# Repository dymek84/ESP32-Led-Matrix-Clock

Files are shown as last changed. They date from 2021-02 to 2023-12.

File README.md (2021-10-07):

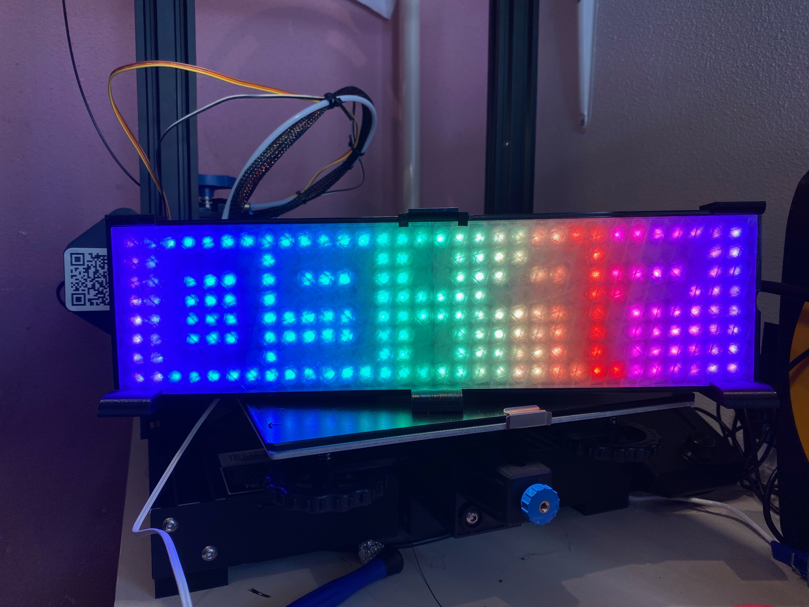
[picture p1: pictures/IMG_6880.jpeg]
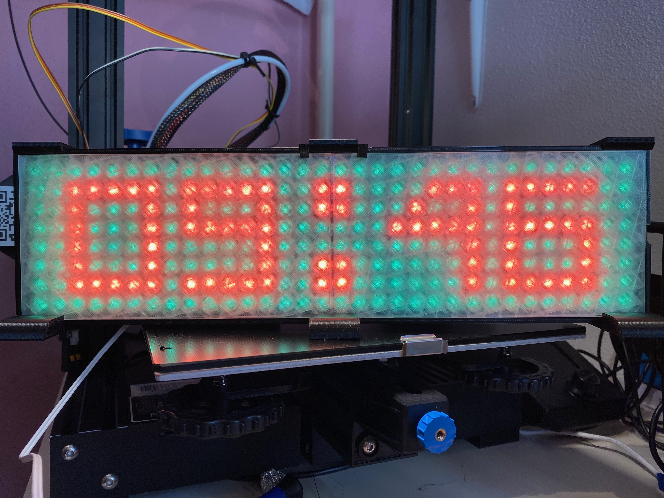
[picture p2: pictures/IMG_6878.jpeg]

(http://www.youtube.com/watch?v=N7SGHlUMIps "")

# ESP32-Led-Matrix-Clock. VERSION 2.0 since March 16-2021
A led matrix clock ran on an ESP32 using FastLED and a led matrix

# How I got to this project
Based on the LED projects by Bitluni (https://bitluni.net) I got excited to use WS2812 (or alike) LED's to create something fun.
After creating my LED Pingpong Ball light I wanted something else. So I stumbled on the LED clock video https://www.youtube.com/watch?v=7urN2OS0fjs by Thomas https://www.instructables.com/Ping-Pong-Ball-LED-Clock/ and https://www.hackster.io/news/improved-led-ping-pong-ball-clock-232a0ac06643
I loved these creations. But... (always a but), this is a BIG clock, a bit too much for my livingroom. Also these clocks run on an arduino and I wanted to use an ESP32.
# Why an ESP32? 
In this project I used: Wemos Mini D1 EPS32 and the ESP32 Devkit V1 both work ). https://www.amazon.nl/ESP-32S-Wireless-Bluetooth-Esp8266-CP2102/dp/B07NW8S1ZR
Because it has built-in WIFI, Bluetooth, DualCore, RTC and much much more. Oh, and a lot of program memory.

# Leds (WS2812 8x32 LED matrix)
Also, I was looking into alternatives to ping-pong balls and LED-strips with smaller LED spacings. The ones used in the projects above are all 30 LEDS per meter. Luckely there are also LED strips with 60 and 144 LED's per meter. Downside, the pingpong balls wont fit. And while searching for these strips my eye caught an alternative, a WS2812 LED MATRIX, available in the sizes 8x8 (too small for this project, unless you buy 4), 16x16 (yes nice) and an 8x32 (great!!) version. I bought the latter. I bought mine at (https://www.tinytronics.nl/shop/en/lighting/led-digital/ws2812b-digitale-5050-rgb-led-matrix-32x8-flexible) but you can get it a lot cheaper on one of the chinese stores.  Please note. This project doesn't depend on using this specific matrix. You can create your own, or buy for example 4 8x8 LED matrices and even any other addressable LED can be used, as long as it is supported by the FastLED library (http://fastled.io).

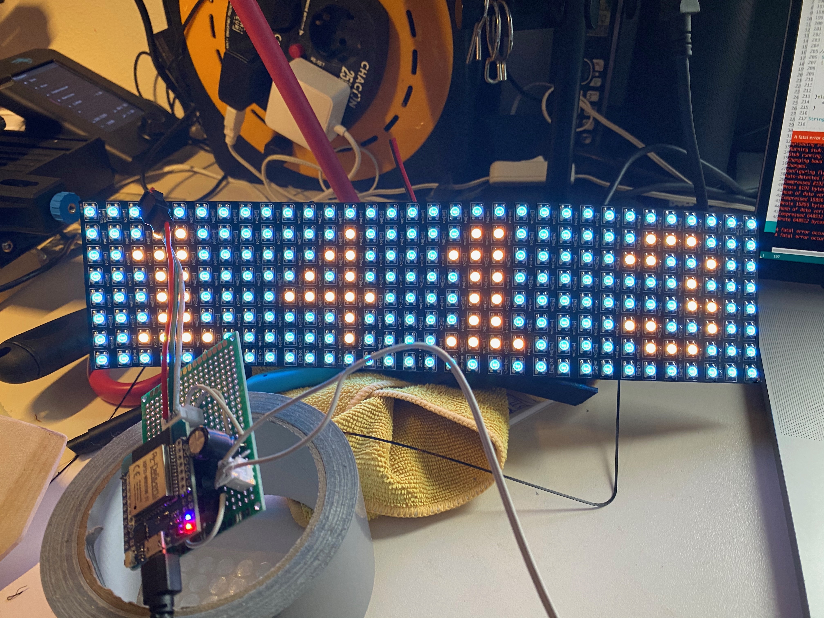
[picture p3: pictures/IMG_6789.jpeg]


# 3D printer files, equipment and settings.
As ping pong balls don't fit and as I also just bought a 3D printer, I really wanted to make use of that. After a crash course in fusion 360 design, I created an enclosure for the matrix and ESP32. An OMG, It looks great!! The Fusion 360 files (or printable obj files) will be shared here as well. For you to use and change in anyway you like. Please know, I'm not a fusion 360 specialist, by far, so non parametric, ugly sketches and a lot of .. how did I do this moments, went into designing. 
The enclosure was printed using Black PLA and the LED diffusor using Neutral (almost transparent) PLA. (neutral: https://www.123-3d.nl/PLA/1-75-mm-PLA/Neutraal-p7318.html, black: https://www.123-3d.nl/PLA/1-75-mm-PLA/Zwart-p7316.html).  
Everything was printed on a Creality Ender 3v2: https://www.123-3d.nl/3D-printers/Creality-3D-Ender-3-V2-p16058.html accomodated with a BL-touch. (Using the superb modded Marlin firmware provided by Smith3D : https://smith3d.com/ender-3-v2-bltouch-firmware-installation-guide-by-smith3d-com/)
All fusion 360 files were sliced using CURA 4.7.  As the enclosure is a little bit bigger then the printbed (32 cm vs 22.5 cm) I designed it such that it is printed in 2 pieces and glued together afterwards. The same for the diffusor. Everything was printed at standard quality (0.4 nozzle and 0.2 layer height) except for the stands, these were printed at 0.28 layer height, which didn't affect the quality because of their simplicity. 

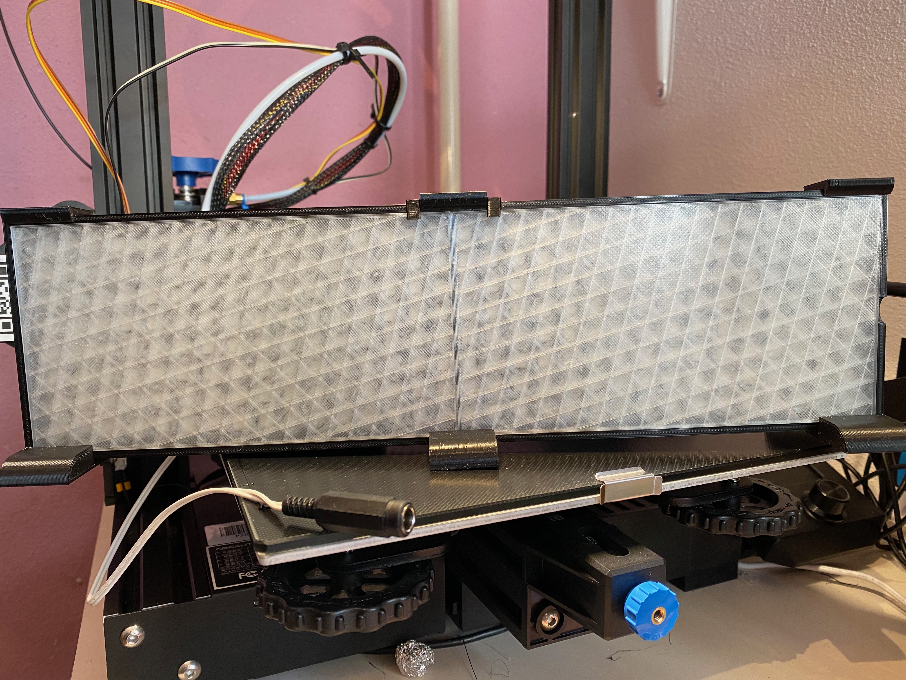
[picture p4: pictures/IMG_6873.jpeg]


# Coding and stuff
First of all, I'm not a software engineer. I did a lot of programming in the past, mostly in [R], Java, PHP and Perl. I'm a bioinformatician, who mostly does biological data analysis using scripts and a bit of ugly code. Don't expect a neatly programmed project. I tried to put comments in the code and splitted the Arduino.ino files into seperate files, each with their own 'focus'. So no libraries. In the end the arduino environment will concatenate all files into one big file and compile it. 
I used a lot of global variables. Some lineair thinking and ugly if loops. And when possible put repeated code in functions. Those are my design choices. Not the best, but they get the job done. I invite you, if you like this project, to make it better, faster and more efficient!!! 
## It is open source, but please if you make any improvements or create your own version in the end, please acknowledge me and share the code with me. 
- Use the Arduino programming environment and make sure to Add the ESP32 to your libraries and boards, see tutorial: https://randomnerdtutorials.com/installing-the-esp32-board-in-arduino-ide-windows-instructions/
- You can import my sketch in this environment. If correct, all files should be in there!! Don't change the file names (and yes, I used numbering and some numbers my be missing, this is deliberary a I might want to add stuff later on..) The order is important!! All files should be in TABS in the arduino project onces it is opened. 
- I have used a lot of libraties: Make sure you have them all installed in the arduino environment:
#include <FastLED.h>                                  // No animations without this library
#include <WiFi.h>                                     // No wifi without this library
#include "Time.h"                                     // And how about the time.. no idea what time it is without this library
#include <String>
#include <AsyncTCP.h>                                 // Webserver stuff
#include <ESPAsyncWebServer.h>                        // More webserver stuff
#include <HTTPClient.h>                               // Needed to get some information from the internetz.. .like weather data  
#include <AsyncElegantOTA.h>                          // A library to allow Over The Air Updates :)
#include <Arduino_JSON.h>                             // Often this data comes as JSON :)
#include "soc/soc.h"                                  // Used to make taksk on diferent cores
#include "soc/rtc_cntl_reg.h"
#include <Preferences.h>                              // Store the prefences in permanent memory in a much easier way than SPIFFS
#include "HTML.h"                                     // A library containing the HTML pages (included with this project)
#include "MatrixDefs.h"                               // A library containing the arrays with matrix defenitions, eg xy positions etc. IMPORTANT as
#include <map>                                        // We will use hashmaps to store Led position and color data
  
Issues I have encountered on my Mac (OSX 11.2.1) when trying to compile in arduino are...:
- Almost after every OSX update I get error messages that compiling is not possible: Run this in the terminal --> sudo xcode-select --install
- Not seeing the ESP32 on the serial port: https://www.silabs.com/developers/usb-to-uart-bridge-vcp-drivers install the correct UART drivers (2102)
- Some ESP32 (not the mini I used) have two buttons, one (boot) must be pressed when uploading your compiled sketch! The ESP32 wemos mini I used does this automatically.
- This guide: https://randomnerdtutorials.com/esp32-troubleshooting-guide/ helped me basically with all issues.

Important:
The first .ino file (called LEdMatrixESP2) contains all globals and settings for the LED types used, amount of LED's, the max current and voltage used, and on which ESP32 pin(s) the LED's are connected. Make sure everything is correct. 
More over the ledArray[XRES * YRES] is THE place to configure your matrix. It basically tells which LED number is on which X,Y coordinate. As this may differ between led matrices.  Mine for example was a up/down/down/up/up...etc configuration. This part is some hand-work. For sure somebody may have a smarter and more mathematical approach. Well this works for me.   The numberMatix stores the number characters.. Which in this case are actually 6x6 pixel characters in a 8x8 array (64). You can create your own font if you like, but just changing the 0 and 1 at specific positions. 
Also in this file you find the HTML pages that are served to configure the clock once it is up and running.

#So what does it do (or what did I implement).
1. After uploading the compiled sketch to the ESP32 or after booting up/restart..
2. The ESP32 will power-up. And after a few seconds on the top left a LED will turn on. And under that light more leds will turn. One more for every time that the ESP will try to connect to (a) your wifi router. If this after 5 tries (~15 seconds) does not work, the ESP32 will boot up as ACCESSPOINT (see 2.1)
2.1 Depending on the first time boot, there will be no WIFI (SSID,PWD) configured. So the ESP32 will start as an accesspoint. You will see it appear as: ESP32-LedMatrixClock and the password is 1234abcd.  Logon to this wifi and open the browser 192.168.4.1 will probably the IP address of the ESP32. (If this doesn't work, connect to the serial monitor, the IP-address will be shown there as wel). On this webpage, enter the station SSID (you will not see a list, so know you names), press submit. Next enter your station password and press submit. Finally press the reboot button. If you entered everyting correctly. The ESP32 can now connect to your own WIfI router.
2.2. If connected to your wifi station (router). The LED on the matrix will turn green. 
3. The ESP32 will display a 1 or 2 or 3 digit number. Those are the last 3 numbers of it's IP address. Most often the IP address will be 192.168.1.xxx (where xxx is the number on the matrix). In case you have a very different router DNS config, you should connect your clock to the serial monitor, and there the full IP address will be shown.  
4. A 3rd LED will light-up orange, this is the ESP32 tryiing to get the time from the NTP server: europe.pool.ntp.org (change NTP server if need be in the sketch).
Sometimes the NTP server doesn't respond. The ESP32 will try 5 times (~15-20 seconds) before it decides to give up and reboot. A reboot often does the trick. Also have a look at the NTP server settings.. it is now set to the NL timezone with Daylight Saving enabled.
5. If network time is configured the time will be shown on the matrix. 
6. Now you can surf to the ESP's ip address and play with the configuration, change animations, LED colors, set a night mode, or choose for a random animation to be shown at specific intervalls. 

# Work in progress: 
There are so many things I want to do. But for now this is my action list.

- DONE: Configure colors background and letters.
- DONE: Choose an animation for the background or digits.
- DONE: Set a text on the website and display it on the matrix.		
- DONE: Random animation at a given time intervall op 60, 30, 15, 1 minutes.
- DONE: Nightmode with red letters (dim) and no background. 
- DONE: Sleep and wakeup times for nightmode.. (limited to specific times for now)
- DONE: Option to globally dim the display, and seperate dimming options for characters and background.
- ONGOIN: More animation
- DONE: Access Point mode to configure WIFI 
- DONE: Show IP address on bootup
- Characters can now only be placed based on X position, not Y position yet.
- DONE: Add photo's to this page
- IMPLEMENTED: a more simple method to animate background and foreground without them inteferring..(most of the time).
- IMPLEMENTED: Light Dependent Resistor input to automticallt accomodate the brightness of the matrix to the ambient brightness
- IMPLEMENTED: New animation. Now when a minute or hour has passed the corresponding digit scrolls down and is replaced by a new digit.
- Added Over The Air (OTA) update capability.. go to the clock settings webpage http://yourclock.ip.address/update/ and upload a pre compiles binary

-- ISSUE (or not): When background is fade-down, some animations will not look as good. As a fix some background cannot be faded (even if you set it to fade) the only dimming that will always work is the overall brightness (dimming). 
-- The code for this version 2.0 is way more structured. But still at some points spaghetti.. but its faster and easier to read (more comments inline) and better use of functions().

# Wires and schema's

In the (bad) photo you see how I soldered everyting on a soldering breadboard. (5cm x 7 cm). 
On the ESP32 I soldered pins on the ground, Pin2 and 5V places. And on the right side row two pins, one on the top and one on the bottom of the outer rows. Note: Pin2 was used in version 1, for version 2 I used pin 18. You can still use 2, 18 or any other pin, just set it correct in the code!! #define DATA_PIN .. (where .. is your data pin number)
Also, now I have added a Light Dependent Resistor, on PIN 34 (again, you can choose something else). It enables the matrix to adjust the brightness according to the ambient brightness. Its based on a voltage devider schema. Resistance of the photoresistor is typically less than 80 Ohms (< 80Ω) in full light and Dark resistance is typically greater than 20 Meg Ohms (> 20MΩ) – when the photoresistor is in full darkness. IMPORTANT: You need to drill a hole in the enclosure of the CPU-holder to fit the LDR through!
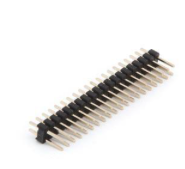
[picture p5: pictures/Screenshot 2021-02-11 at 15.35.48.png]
((Pins, also called male Pin Header,  you can break of seperate pins ;
This makes a square of pins. In this way every corner connects to the sockets on the breadboard and this makes it more stable.
On the soldering breadbord I soldered the sockets/connectors. This makes the ESP32 plug and play in case you want to add, change stuff.
I used JST XH connectors to allow easy plugin and removal of the connections to the powersupply and the matrix.
Under the ESP, I soldered the 62 Ohm resistor, this makes the data signal cleaner. I used https://github.com/Aircoookie/WLED/wiki this schema as reference.
Also a 1000uF capacitor (rated for 5V-12V and 50Watt) was used to catch possible power fluctuations. This can happen when some funcions, or effects on the matrix draw for a short time more power. This prevent so called Brownouts on the ESP32, causing it to reboot.
With 256 LED's each consuming a max of 40 mili-Amps (fully on white), you need 10 Amps at 5V (50Watt). In the code I limited to 3 Amps. This seems to be sufficient for what this clock does. It is still bright and works like a charm.
I use powerinjection.. so prevent to not feed the Leds via the ESP32, but just like I did in this schema. The Matrix that I have has 3 connectors, I powerinject over every connector to prevent voltagedrops and hence bad color representation.

Have fun....

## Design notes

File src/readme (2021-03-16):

This is version 2.0 of the Led Matrix Clock Aruino code. Many enhancements have been implemented. For better performance and more flexibility.

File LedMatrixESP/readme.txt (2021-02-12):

All *.ino files are part of one Sketch. So don't delete any of them. 
When you put everyting in a LedMatrixESP foler in the ardiuno projects folder and open LedMtrixESP.ino the other files should become visible as tabs.

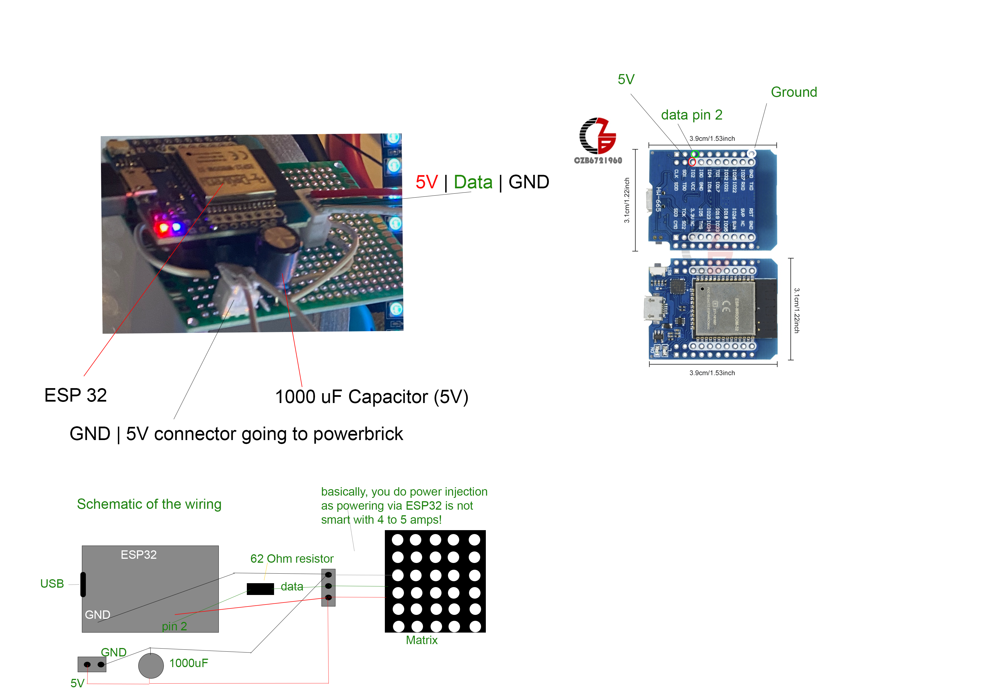
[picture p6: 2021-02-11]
pictures/ESP-schema.png

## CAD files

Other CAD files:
LedLamp v63.f3d

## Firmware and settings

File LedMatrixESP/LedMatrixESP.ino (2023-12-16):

/*
  LedMatrixESP - Clock
  This is a sketch made by: Bas van Breukelen, Arnhem Netherlands.
  This sketch is, "as it is" and made to run on a ESP32 (AZ-delivery ESP32-WROOM-32,  mini was used for development)
  The inital project was a 8x32 (256) ledMatrix, to run a a clock, updated via NTP and configurable via WiFi
  I have used effects as found on several webistes: like https://www.tweaking4all.com/hardware/arduino/adruino-led-strip-effects/#FastLEDFramework
  Plus what I can create myself. The script have been modified to fit my needs
  I also used https://randomnerdtutorials.com/esp32-esp8266-input-data-html-form/ to setup the basics of the webserver
  To make things (hopefully) more efficient I run the webserver on the second core of the EPS using this tutorial: https://randomnerdtutorials.com/esp32-dual-core-arduino-ide/
  LedMatrix: 8x32 matrix (ali-express), 256 WS2812 pixels.
  FastLed library runs it all
*/

#include <FastLED.h>
#include <WiFi.h>
#include "time.h"
#include <String>
#include <AsyncTCP.h>
#include <ESPAsyncWebServer.h>
#include <SPIFFS.h>
#include "soc/soc.h"
#include "soc/rtc_cntl_reg.h"


#define NUM_LEDS 256
#define DATA_PIN 2 //GPIO2 on ESP32
#define BRIGHTNESS 255
#define XRES 32
#define YRES 8
#define VOLTAGE 5 //5 volt strip
#define AMPS 5000 //5 AMP (or 5000 mAmp powerbrick used)

#define qsubd(x, b)  ((x>b)?b:0)                              // Digital unsigned subtraction macro. if result <0, then => 0. Otherwise, take on fixed value.
#define qsuba(x, b)  ((x>b)?x-b:0)                            // Analog Unsigned subtraction macro. if result <0, then => 0

#define maxRipples 6                                                            // Min is 2 and value has to be divisible by two because each ripple has a left and right component. This cuts down on bouncing code.


// We will store PWD and SSID in these variables.
const char* ssid;
const char* password;

//in case we cannot connect to a wifi station we will create an accesspoint and serve a page to configure wifi access.
const char* ssidAP = "ESP32-LedMatrixClock";
const char* passwordAP = "1234abcd";
boolean APmode = false;
boolean newWifiSet = false;

//wifi server
AsyncWebServer server(80);
const char* PARAM_MESSAGE = "message";


// As this led matrix clock need to know the time....
const char* ntpServer = "europe.pool.ntp.org"; //this is a general Network Time Server
const long  gmtOffset_sec = 3600; // we live in UTC+1H
const int   daylightOffset_sec = 3600; // yes NL has daylight savings
int second;
int minute;
int hour;
int day;
int month;
int year;
int weekday;
long current;
struct tm timeinfo;


// We will be doing a lot with colors, and configuring colors.. And therefore need some variables to store them
CRGB timeColor = CRGB::Red;
CRGB digitColor = CRGB::Red;
CRGB backgroundColor = CRGB::Green;
String currentAnimation;
bool breakAnimation = false;
//CRGBPalette16 currentPalette;
//TBlendType    currentBlending;
extern CRGBPalette16 myRedWhiteBluePalette;

// Palette definitions
CRGBPalette16 currentPalette;
CRGBPalette16 targetPalette;
TBlendType    currentBlending = LINEARBLEND;


uint8_t hue = 0;
uint8_t mhue = 171;
uint8_t backgroundBrightness = 128; //not start full on but at 50%
uint8_t digitBrightness = 128; //not start full on but at 50%
uint8_t overAllBrightness = 128; //not start full on but at 50%, this prevents a brownout by drawinf too much current.
boolean nightMode = false;
int nightTimeHour = 22;
int nightTimeMinute = 00;
int morningTimeHour = 7;
int morningTimeMinute = 00;
int getallenZwart = 0;

/* some variable for an other FX library */
uint8_t  thisfade = 8;                                        // How quickly does it fade? Lower = slower fade rate.
int       thishue = 50;                                       // Starting hue.
uint8_t   thisinc = 1;                                        // Incremental value for rotating hues
uint8_t   thissat = 100;                                      // The saturation, where 255 = brilliant colours.
uint8_t   thisbri = 255;                                      // Brightness of a sequence. Remember, max_bright is the overall limiter.
int       huediff = 256;                                      // Range of random #'s to use for hue
uint8_t thisdelay = 5;                                        // We don't need much delay (if any)

// dots_beat
uint8_t   count =   0;                                        // Count up to 255 and then reverts to 0
uint8_t fadeval = 224;                                        // Trail behind the LED's. Lower => faster fade.

uint8_t bpm = 30;

// The nice thing about ESp32 is 2 cores.. so let's make use of both.
TaskHandle_t Task1;
TaskHandle_t Task2;


// We 'translate' the led matrix pixels into X and Y coordinated.. And the cursor will determine where we will place our characters..
int locationCursorX = 0; // our first pixel X is 0
int locarionCursorY = 0; // our first pixel Y is 0


/*
   HTML web page to handle our input fields.
   there are two (main) pages. The index_html is what is served to configure animations, colors and led matrix settings
   the index2_html is served only when the ESP32 is in AccessPoint mode, to configure wifi ssid and pwd.

   All variables that we use are stored in SSPID memory (stored even after power off). The writeFile() and readFile() function need to
   be updated when new variables (input fields) are added! Also the processor() function needs to be updated with the new inputs.

   As these pages need to be here before any script calls upon them, here is were we define them
*/

const char index_html[] PROGMEM = R"rawliteral(
<!DOCTYPE HTML><html><head>
  <title>ESP32 Led Matrix Clock</title>
  <meta name="viewport" content="width=device-width, initial-scale=1">
  <script>
    function submitMessage() {
      alert("Saved value to ESP SPIFFS");
      setTimeout(function(){ document.location.reload(false); }, 500);   
    }
  </script></head><body>
  <form action="/get" target="hidden-form">
    Kies je effect: nu %inputString% <br />
      <select name="inputString" id="effecten" onchange="this.form.submit()">
      <option value="%inputString%" selected> %inputString% </option>
        <option value="oneColorBackground">Fixed Background </option>
        <option value="randomEveryHour">Random ieder uur </option>
        <option value="randomEveryHalf">Random ieder half uur </option>
        <option value="randomEvery15">Random ieder 15 minuten </option>
         <option value="rainbowCycle">Regenbook achtergrond</option>
         <option value="sparkle">Glitter</option>
         <option value="runningLights">Rennend licht</option>
          <option value="colorWipe">Kleuren Wisser</option>
           <option value="Sneeuw">Sneeuw</option>
            <option value="randomTwinkle">kleuren twinkels</option>
            <option value="MeteorRain">Meteoor</option>
            <option value = "bouncing">Stuiterende Ballen</option>
            <option value = "confetti">confetti</option>
            <option value = "plasma">Plasma</option>
            <option value = "ripples">ripples</option>
            <option value = "raibowWaves">Regenboog golven</option>
            <option value = "dotsBeat">Dots</option>
      </select>
  </form><br />
  
  <form action="/get" target="hidden-form">
    Klok cijfers aan/uit:  <br />
    <select name="inputInt" id="%inputInt%" onchange="this.form.submit()">
    <option value="%inputInt%" selected> %inputInt% </option>
    <option value="1">Aan (1)</option>
    <option value="0">Uit (0)</option>
    <option value="2">Regenboog (2)</opion>
    </select>
  </form><br />
  
  <form action="/get" target="hidden-form">
    <label for="colorpicker1">Kies de kleur van je cijfers</label> <br />
    <input type="color" id="colorpicker1" name="inputDigitCol" value ="%inputDigitCol%">
    <input type="submit" value="Submit" onclick="submitMessage()">
   </form><br />
   
    <form action="/get" target="hidden-form">
    <label for="colorpicker2">Kies de kleur van je achtergrond</label> <br />
    <input type="color" id="colorpicker2" name="inputBGCol" value ="%inputBGCol%">
    <input type="submit" value="Submit" onclick="submitMessage()">
   </form><br />

    <form action="/get" target="hidden-form">
    <label for="helderheid" name="overAllBrightness">Pas de helderheid van de hele matrix aan </label> <br />
    <select name="overAllBrightness" id="overAllBrightness" onchange="this.form.submit()">
      <option value="%overAllBrightness%" selected> %overAllBrightness% </option>
        <option value="100">100 </option>
         <option value="75">75 </option>
        <option value="50">50 </option>
        <option value="25">25 </option>
    </select>
    </form>

 <form action="/get" target="hidden-form">
    <label for="achergrondhelderheid" name="backgroundBrightness" >Pas de helderheid van de achtergrond aan (werkt niet voor alle effecten)</label> <br />
    <select name="backgroundBrightness" id="backgroundBrightness" onchange="this.form.submit()">
      <option value="%backgroundBrightness%" selected> %backgroundBrightness% </option>
        <option value="100">100 </option>
        <option value="75">75 </option>
        <option value="50">50 </option>
        <option value="25">25 </option>
        <option value="12">12 </option>
    </select>
    </form>

     <form action="/get" target="hidden-form">
    <label for="cijfershelderheid" name="digitBrightness">Pas de helderheid van de cijfers aan </label> <br />
    <select name="digitBrightness" id="digitBrightness"  onchange="this.form.submit()">
      <option value="%digitBrightness%" selected> %digitBrightness% </option>
        <option value="100">100 </option>
         <option value="75">75 </option>
        <option value="50">50 </option>
        <option value="25">25 </option>
        <option value="12">12 </option>
    </select>
    </form>
   
   <form action="/get" target="hidden-form">
   Handmatige nachtstand:<br />
    <select name="nightMode" id="nachtstand" onchange="this.form.submit()">
      <option value="%nightMode%" selected> %nightMode% </option>
        <option value="Ja">Ja </option>
        <option value="Nee">Nee </option>
    </select>
    </form>
<br />
De nachtstand kan ook automatisch aan en uitgezet worden, kies een begin tijd en een eindtijd.
<form action="/get" target="hidden-form">
   Nachtstand starten om: (uur) <br />
    <select name="nightTimeHour" id="nightTimeHour" onchange="this.form.submit()">
      <option value="%nightTimeHour%" selected> %nightTimeHour% </option>
        <option value="19">19</option>
        <option value="20">20</option>
        <option value="21">21</option>
        <option value="22">22</option>
        <option value="23">23</option>  
    </select>
     </form>
    <form action="/get" target="hidden-form">
   Nachtstand starten minuut: 
    <select name="nightTimeMinute" id="nightTimeMinute" onchange="this.form.submit()">
      <option value="%nightTimeMinute%" selected> %nightTimeMinute% </option>
        <option value="0">0</option>
        <option value="5">5</option>
        <option value="10">10</option>
        <option value="15">15</option>
        <option value="20">20</option>
        <option value="25">25</option>
        <option value="30">30</option>
        <option value="35">35</option>
        <option value="40">40</option>   
        <option value="45">45</option>
        <option value="50">50</option> 
        <option value="55">55</option>  
    </select>
    </form>
   <form action="/get" target="hidden-form">
   Nachtstand STOPPEN om: (uur) <br />
    <select name="morningTimeHour" id="morningTimeHour" onchange="this.form.submit()">
      <option value="%morningTimeHour%" selected> %morningTimeHour% </option>
        <option value="5">5</option>
        <option value="6">6</option>
        <option value="7">7</option>
        <option value="8">8</option>
        <option value="9">9</option>
        <option value="10">10</option>
        <option value="11">11</option>
            
    </select>
     </form>
    <form action="/get" target="hidden-form">
   Nachtstand STOPPEN minuut: 
    <select name="morningTimeMinute" id="morningTimeMinute" onchange="this.form.submit()">
      <option value="%morningTimeMinute%" selected> %morningTimeMinute% </option>
        <option value="0">0</option>
        <option value="5">5</option>
        <option value="10">10</option>
        <option value="15">15</option>
        <option value="20">20</option>
        <option value="25">25</option>
        <option value="30">30</option>
        <option value="35">35</option>
        <option value="40">40</option>   
        <option value="45">45</option>
        <option value="50">50</option> 
        <option value="55">55</option>  
    </select>
     </form>
     <br />Tussen %nightTimeHour%:%nightTimeMinute% in de avond en %morningTimeHour%:%morningTimeMinute%  in de ochtend<br />
     zal de klok in nachtstand staan. <br />
    <iframe style="display:none" name="hidden-form"></iframe>
</body></html>)rawliteral";

// Webpage that is served when ESP is in case accessmode:
const char index2_html[] PROGMEM = R"rawliteral(
<!DOCTYPE HTML><html><head>
  <title>Matrix Clock, Accesspoint... Swtup mode</title>
  <meta name="viewport" content="width=device-width, initial-scale=1">
  <script>
    function submitMessage() {
      alert("Saved value to ESP SPIFFS");
      setTimeout(function(){ document.location.reload(false); }, 500);   
    }
  </script></head><body>
  <form action="/get" target="hidden-form">
    Wat is de naam van je wifi station: ( %inputWifi% ) <br /> 
    Druk op submit als je een nieuwe naam hebt ingevoerd. Voer daarna pas een wachtwoord in.<br />
    <input type="text " name="inputWifi" value="%inputWifi%">
    <input type="submit" value="Submit" onclick="submitMessage()">
  </form><br>
  <form action="/get" target="hidden-form">
    Wat is het wachtwoord van je wifi station <br />
    <input type="password " name="inputPWD" value="%inputPWD%">
    <input type="submit" value="Submit" onclick="submitMessage()">
  </form><br>
  <form action="/get" target="hidden-form">
  Druk op deze knop als je een nieuw wachtwoord en ssid hebt opgegeven <br />
  <input type="submit" value="Start opnieuw op" onclick="submitMessage()">
  <br />
  <br /> Made by Bas van Breukelen (c) 2021
  <iframe style="display:none" name="hidden-form"></iframe>
</body></html>)rawliteral";


// this will contain (later) all options for the animations
const char* PARAM_STRING = "inputString";
const char* PARAM_INT = "inputInt";
const char* PARAM_FLOAT = "inputFloat";
const char* PARAM_WIFI = "inputWifi";
const char* PARAM_PWD = "inputPWD";
const char* PARAM_COL1 = "inputDigitCol";
const char* PARAM_COL2 = "inputBGCol";
const char* PARAM_NIGHTMODE = "nightMode";
const char* PARAM_NIGHTHOUR = "nightTimeHour";
const char* PARAM_NIGHTMIN = "nightTimeMinute";
const char* PARAM_MORNINGHOUR = "morningTimeHour";
const char* PARAM_MORNINGMINUTE = "morningTimeMinute";
const char* PARAM_OVERALLBRIGHTNESS = "overAllBrightness";
const char* PARAM_BGBRIGHTNESS = "backgroundBrightness";
const char* PARAM_DIGITBRIGHTNESS = "digitBrightness";


// end stuff for webserver



/*
    preapare the matrix
    Below we create a (one dimentional) array where we basically for each x,y position put the LED number. In this way, you can acoomodate for
    any setup of leds. ZigZag, Or Left to right, right to left, up/down or combination of multiple matrices.

*/
CRGB matrix[NUM_LEDS];


const int ledArray[XRES * YRES] = // the order of led-id's in this case every row is left to right.
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
void loop() {

  // All our parameters that can be changes from the webpage are stored in SPIFFS
  if (!SPIFFS.begin(true)) {
    Serial.println("An Error has occurred while mounting SPIFFS");
    return;
  }



  /* nightMode can be switched on manually
      but also set for a start and end time (hours and minutes)
  */
  

  if (timeinfo.tm_hour > 12 && timeinfo.tm_hour <= 23 && timeinfo.tm_hour >= nightTimeHour && timeinfo.tm_min >= nightTimeMinute ) { // it is evening, and the NightLamp time is passed.
    EveningSleep = true;
  } else {
    EveningSleep = false;
  }
  if (EveningSleep == true && timeinfo.tm_hour >= 0 && timeinfo.tm_hour < 12 && timeinfo.tm_hour >= morningTimeHour && timeinfo.tm_min <= morningTimeMinute) { // wake-up
    Nachtlamp = false;
    EveningSleep = false;
  } else if (EveningSleep == false) {
    Nachtlamp = false;
  } else {
    Nachtlamp = true;
    //  Serial.println("Nachtlamp = true");
  }

  /*
     Based on the animation selected.. let's display this
     A lot of the interrupts (when we select a diferent animation or setting is done by the second processor..
     In the function called Task1code
  */

  if (Nachtlamp == true || nightMode == true) {
    //Serial.println("Nachtmode");
    nachtmode();
  } else {

    String whichFX = currentAnimation;
    if (whichFX == "oneColorBackground") {
      // setAll(0, 0, 0);
      oneColorBackground(backgroundColor, backgroundBrightness);
    } else if (whichFX == "rainbowCycle") {
      rainbowCycle(20);
    } else if (whichFX == "sparkle") {
      //setAll(0, 0, 0);
      Sparkle(0xff, 0xff, 0xff, 0);
    } else if (whichFX == "runningLights") {
      setAll(0, 0, 0);
      RunningLights(0xff, 0, 0, 50);      // red
      RunningLights(0xff, 0xff, 0xff, 50); // white
      RunningLights(0, 0, 0xff, 50);      // blue
      breakAnimation = false;
    } else if (whichFX == "colorWipe") {
      setAll(0, 0, 0);
      colorWipe(0x00, 0xff, 0x00, 50);
      colorWipe(0x00, 0x00, 0x00, 50);
      breakAnimation = false;
    } else if (whichFX == "Sneeuw") {
       int tempbackground = backgroundBrightness; //store gloval background.
      backgroundBrightness = 0;
      //    setAll(0,0,0);
      SnowSparkle(0x10, 0x10, 0x10, 20, random(100, 1000));
      backgroundBrightness = tempbackground;
    } else if (whichFX == "randomTwinkle") {
      setAll(0, 0, 0);
      TwinkleRandom(40, 200, false);
    } else if (whichFX == "MeteorRain") {
      meteorRain(0xff, 0xff, 0xff, 10, 64, true, 30);
    } else if (whichFX == "bouncing") {
      byte colors[3][3] = { {0xff, 0, 0},
        {0xff, 0xff, 0xff},
        {0   , 0   , 0xff}
      };
      BouncingColoredBalls(3, colors);

    } else if (whichFX == "randomEveryHour") {
      runRandomAnimation(60);
    } else if (whichFX == "randomEveryHalf") {
      runRandomAnimation(30);
    } else if (whichFX == "randomEvery15") {
      runRandomAnimation(15);
    } else if (whichFX == "confetti") {
      int tempbackground = backgroundBrightness; //store gloval background.
      backgroundBrightness = 0;
      ChangeMe();
      EVERY_N_MILLISECONDS(thisdelay) {                           // FastLED based non-blocking delay to update/display the sequence.
        confetti();
      }
      showStrip();
       backgroundBrightness = tempbackground;
    } else if (whichFX == "plasma") {
      int tempbackground = backgroundBrightness; //store gloval background.
      backgroundBrightness = 0;
      currentPalette = OceanColors_p;
      EVERY_N_MILLISECONDS(50) {                                  // FastLED based non-blocking delay to update/display the sequence.
        plasma();
      }
      EVERY_N_SECONDS(5) {                                 // Change the target palette to a random one every 5 seconds.
        uint8_t baseC = random8();                         // You can use this as a baseline colour if you want similar hues in the next line.
        targetPalette = CRGBPalette16(CHSV(baseC + random8(32), 192, random8(128, 255)), CHSV(baseC + random8(32), 255, random8(128, 255)), CHSV(baseC + random8(32), 192, random8(128, 255)), CHSV(baseC + random8(32), 255, random8(128, 255)));
      }
      showStrip();
       backgroundBrightness = tempbackground;
    } else if (whichFX == "ripples") {
       int tempbackground = backgroundBrightness; //store gloval background.
      backgroundBrightness = 0;
      currentPalette = OceanColors_p;                                   // Use palettes instead of direct CHSV or CRGB assignments
      targetPalette = RainbowColors_p;                                    // Also support smooth palette transitioning

      EVERY_N_MILLISECONDS(50) {                                                      // Smooth palette transitioning runs continuously.
        uint8_t maxChanges = 24;
        nblendPaletteTowardPalette(currentPalette, targetPalette, maxChanges);
      }

      EVERY_N_SECONDS(5) {
        SetupMySimilar4Palette();                                                     // Change palette colours every 5 seconds.
      }

      EVERY_N_MILLIS(50) {                                                            // Sets the original delay time.
        rippless();                                                                   // Run the ripple routine.
      }
      showStrip();
        backgroundBrightness = tempbackground;
    } else if (whichFX == "raibowWaves") {
      currentPalette = RainbowColors_p;
      beatwave();

      EVERY_N_MILLISECONDS(100) {
        uint8_t maxChanges = 24;
        nblendPaletteTowardPalette(currentPalette, targetPalette, maxChanges);   // AWESOME palette blending capability.
      }

      EVERY_N_SECONDS(5) {                                        // Change the target palette to a random one every 5 seconds.
        targetPalette = CRGBPalette16(CHSV(random8(), 255, random8(128, 255)), CHSV(random8(), 255, random8(128, 255)), CHSV(random8(), 192, random8(128, 255)), CHSV(random8(), 255, random8(128, 255)));
      }

      showStrip();
    } else if(whichFX = "dotsBeat"){
      dot_beat();
      showStrip();
    } else {
      // we can use this place to also test new animation :)
      setAll(0, 0, 0);
      oneColorBackground(CHSV(10, 255, 64), backgroundBrightness);
    }
  }
}

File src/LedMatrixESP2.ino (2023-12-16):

/*
   Led Matrix Clock, using and ESP32, version 2.0
   This is a rewrite of the initial code for the LedMartrixESP code
   https://www.tutorialspoint.com/esp32_for_iot/esp32_for_iot_preferences.htm
   Clock design and programming (albeit a lot of code snippets are thanks to the great examples on internet)
    (c) Bas van Breukelen, 2021  Version 2.0
*/

/*
   Library Space
*/
#include <FastLED.h> // No animations without this library
#include <WiFi.h>    // No wifi without this library
#include "Time.h"    // And how about the time.. no idea what time it is without this library
////include <Time.h>
// include <TimeAlarms.h>
#include <String>
#include <AsyncTCP.h>          // Webserver stuff
#include <ESPAsyncWebServer.h> // More webserver stuff
#include <HTTPClient.h>        // Needed to get some information from the internetz.. .like weather data
#include <ElegantOTA.h>        // A library to allow Over The Air Updates :)
#include <Arduino_JSON.h>      // Often this data comes as JSON :)
#include "soc/soc.h"           // Used to make taksk on diferent cores
#include "soc/rtc_cntl_reg.h"
#include <Preferences.h> // Store the prefences in permanent memory in a much easier way than SPIFFS
#include "HTML.h"        // A library containing the HTML pages (included with this project)
#include "MatrixDefs.h"  // A library containing the arrays with matrix defenitions, eg xy positions etc. IMPORTANT as
#include <map>           // We will use hashmaps to store Led position and color data
// you need to edit MatrixDefs.h for YOUR matrix.. Also the digits and characters are defined here..
// SO EDIT that file!!
/*
    Define Space
*/

#define NUM_LEDS 256 // THE NUMBER OF LEDs USED IN THE MATRIX
#define DATA_PIN2 2  // ON WHICH PIN WILL THE DATA BE SEND
#define DATA_PIN12 12
#define DATA_PIN18 18
#define BRIGHTNESS 255                    // INITIAL BRIGHNESS OF THE MATRIX.
#define VOLTAGE 5                         // THE VOLTAGE OUR SYSTEM USES
#define AMPS 5000                         // THE CURRENT THAT YOUR POWERBRICK CAN DELIVER e.g 5 AMP (or 5000 mA)
#define qsubd(x, b) ((x > b) ? b : 0)     // Digital unsigned subtraction macro. if result <0, then => 0. Otherwise, take on fixed value.
#define qsuba(x, b) ((x > b) ? x - b : 0) // Analog Unsigned subtraction macro. if result <0, then => 0

/*
   Global spaceO
   Below all the GLOBAL Variables are stored.
   Whilest we do not want to have too many of those. It cannot always be prevented.
*/
// PREFERENCES
Preferences preferences; // We will store our variables here that we don't want to loose

// WIFI
const char *ssidAP = "ESP32-LedMatrixClock"; // IN CASE WE CANNOT CONNECT TO THE WIFI THE ESP32 WILL PRESENT ITSELF AS AN ACCESSPOINTER USING THIS NAME
const char *passwordAP = "1234abcd";         // AND YOU CAN ACCESS THAT ACCESSPOINT USING THIS SIMPLE PASSWORD
AsyncWebServer server(80);                   // Create AsyncWebServer object on port 80

// Do you have a LDR (light dependent resistor installed? if so, which pin)
const int sensorPin = 34; // AN LDR is installed on PIN 34. (10kOhm between GND and 3.3V on positive side)
boolean useLDR = true;    // THE LDR IS OPTIONAL, IT WILL BE USED TO CONTROL THE OVERALL BRIGHTNESS IS PRESENT
int lightInit;            // initial value
int lightVal;             // light reading

// pins settings from wifi
int ledpin = 0; // We can use preferences to set the PINS to some other setting.
int ldrpin = sensorPin;

// CLOCK&TIME SETTING
const char *ntpServer = "nl.pool.ntp.org"; // THIS IS THE WEB ADDRESS OF THE EUROPEAN NETWORK TIME SERVER
const long gmtOffset_sec = 3600;           // WE LIVE IN THE NETHERLANDS => UTC+1H
const int daylightOffset_sec = 3600;       // YES THE NETHERLANDS IS STILL ON DAYLIGHT SAVINGS
const char *defaultTimezone = "CET-1CEST,M3.5.0/2,M10.5.0/3";
struct tm timeinfo; // TIME OBJECT

//  SETTINGS FOR THE MATRIX LIKE COLORS, BRIGHTNESS, BACKGROUND ETC, THAT CAN BE CHANGES DURING RUNTIME
CRGB digitColor = CRGB::Red;                    // THE INITIAL COLOR OF THE DIGITS IS RED
CRGB backgroundColor = CRGB::Green;             // THE INITIAL COLOR OF THE BACKGROUND IS GREEN
String currentAnimation;                        // THE NAME OF THE ANIMATION THAT PLAYS
bool breakAnimation = false;                    // A BOOLEAN VALUE USED TO STOP AN ANIMATION BEFORE IT REALLY HAS ENDED
CRGBPalette16 currentPalette = RainbowColors_p; // CONTAINER FOR THE COLOR PALETTE USED FOR ANIMATIONS
CRGBPalette16 currentPalette2 = RainbowColors_p;
CRGBPalette16 targetPalette;                // AS ABOVE
CRGBPalette16 targetPalette2;               // AS ABOVE
TBlendType currentBlending = LINEARBLEND;   // CONTAINER FOT THE BLENDINGTYPE USED IN ANIMATIONS
extern CRGBPalette16 myRedWhiteBluePalette; // AN IMPORTED COLOR PALETTE FOR ANIMATION

uint8_t backgroundBrightness = 128; // THE BACKGROUND BRIGHTNESS (ALL LEDS EXCEPT THE DIGITS)
uint8_t digitBrightness = 128;      // THE DIGIT BRIGHNESS (ALL LEDS EXCEPT THE BACKGROUND)
uint8_t overAllBrightness = 128;    // THE OVERALL BRIGHTNESS AFFECTS ALL LEDS.
int ledClockBrightNess = 128;       // IS USED TO SCALE THE LEDCLOCK WHEN A LDR IS USED
boolean nightMode = false;          // IS THE MATRIX IN NIGHT (BEDTIME) MODE
boolean useOld = false;             // WHEN TRUE THE TIMEMATIX WILL TAKE THE LEDs COLOR THAT WAS ALREADY THERE
int scrollspeed = 150;              // DEFAULT TEXT SCROLLING SPEED. LOWER IS FASTER. ITS DEFINED AS A STEP PER XX MILLISECONDS

int nightTimeHour = 22; // THE NEXT SETTINGS ARE USED TO SET A TIME IN BETWEEN THE MATRIX IS IN NIGHTMODE
int nightTimeMinute = 00;
int morningTimeHour = 7;
int morningTimeMinute = 00;
boolean EveningSleep = false;
String digitAnimation = "Aan"; // Aan (=On) means, digits are visible. (Uit is OFF and Regenboog is rainbow fx)
int iRebooted = 0;
int Seconde;
int OldSeconde;
int Minute;
int OldMinute;
int Hour;
int OldHour;
int Day;
int Month;
int Year;
boolean timeChangeAnimation = false; // Animate the time change...
int yloc = 0;                        // y location general counter
int ylocmin = 0;                     // y location for upscrolling time minutes
int ylochour = 0;                    // y location for upscrolling hours
String animatechange = "Yes";        // do we want to use this animation
boolean tenminuteJump = false;       // every 10 minutes we need to move 2 digits!
boolean hourjump = false;            // 10 hours we need to move 2 digits
int ydigit1 = 0;
int ydigit2 = 0;
boolean hourhaschanged = false;
int hydigit1 = 0;
int hydigit2 = 0;

String endpoint = "http://api.openweathermap.org/data/2.5/weather?q=";
String city = "Arnhem";  // This needs to be set via the webinterface.
String apikey;           // This API key will be set via the webinterface
String units = "metric"; // Set to standard, metric or imperial in case you need degrees celsius of F.
String weatherJSON = "{}";
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

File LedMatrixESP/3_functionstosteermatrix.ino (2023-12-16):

// FUNCTIONS

/*
 * Here we start our network connection and check if we actually have an connection.. if not, we go to accesspoint mode.
 */
void connectToNetwork() {

  // Read the WIFI ssid and pwd from memory
  if (!SPIFFS.begin(true)) {
    Serial.println("An Error has occurred while mounting SPIFFS");
    return;
  }
  delay(200);
  // read wifi credentials from memory
  password = readFile(SPIFFS, "/inputPWD.txt").c_str();
  delay(200);
  ssid = readFile(SPIFFS, "/inputWifi.txt").c_str();
  delay(200);
  Serial.println("ESP32 said: I used this for SSID and PWD");
  Serial.println(ssid);
  String wifistation = readFile(SPIFFS, "/inputWifi.txt"); // no idea.. but without this line it doesnt work... weird
  Serial.println(wifistation);
  int netWorkTrys = 0;
  matrix[0] = CRGB (0, 10, 20);
  FastLED.show();
  int ledOn = 1;
  WiFi.begin(ssid, password);

  while (WiFi.status() != WL_CONNECTED ) { // a max try should be specified
    delay(2000);
    matrix[ledOn] = CRGB (0, 10, 20);
    Serial.println("Establishing connection to WiFi..");
    ledOn ++;
    FastLED.show();

    if (netWorkTrys > 5) {
      WiFi.disconnect(true);
      Serial.println("No internet, starting in AP");
      /** Ok no internet, maybes start now in AP mode? */
      WiFiServer server(80);
      Serial.print("SNow setting-up soft access point mode...");
      WiFi.softAP(ssidAP, passwordAP);
      IPAddress IP = WiFi.softAPIP();
      Serial.print("AP IP address: ");
      Serial.println(IP);
      server.begin();
      APmode = true;
      break;
    }
    netWorkTrys++;
  }
  matrix[0] = CRGB::Green;
  Serial.println("Connected to network");
  showIPonLED();
  FastLED.show();
}

/* A function to show the IP-address on the LED ... last 3 digits
 *  very handy, so you don't need the serial monitor for this
 *  most often the ip address iss: 192.168.1.xxx where xxx is shown on the matrix
 *  or xx if only 2 digits are used.
*/
void showIPonLED() {
  /* show last digits IP address */
  String ip = WiFi.localIP().toString();
  String iplast0 = ip.substring(ip.length() - 1);
  String iplast1 = ip.substring(ip.length() - 2, ip.length() - 1);
  String iplast2 = ip.substring(ip.length() - 3, ip.length() - 2);

  int digitBrightness = 128;

  CRGB color = timeColor;
  if (iplast2 == ".") { // a two digit IP
    showCharacter(numberMatrix[iplast1.toInt()], locationCursorX + 16, color, digitBrightness );
    showCharacter(numberMatrix[iplast0.toInt()], locationCursorX + 24, color, digitBrightness );
    // showCharacter(numberMatrix[iplast.toInt()], locationCursorX, color );
  } else if (iplast1 == "."){ // a one digit ip
    showCharacter(numberMatrix[iplast0.toInt()], locationCursorX + 24, color , digitBrightness);
  }
  else { // a 3 digit IP
    showCharacter(numberMatrix[iplast2.toInt()], locationCursorX + 8, color , digitBrightness);
    showCharacter(numberMatrix[iplast1.toInt()], locationCursorX + 16, color, digitBrightness );
    showCharacter(numberMatrix[iplast0.toInt()], locationCursorX + 24, color, digitBrightness );
  }
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

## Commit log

2021-02-11 Fusion 360 archive
    This is the complete Fusion 360 project
    [LedLamp v63.f3d]
2021-02-11 Sketch Archive.
    Extract this sketch in the Arduino folder. Keep the name of the folder the same as the main .ino file (LedMatrixESP).
2021-02-11 Update README.md
    Update wiring schema
2021-02-11 Delete LedMatrixEPS.ino
    Old
2021-02-13 Delete LedMatrixESP-2022-02-10-2.zip
    obsolete
2021-02-16 Add files via upload
    Small bug fixes, added an animation for the digits (colorcycle)
    [4_Functionstoshowtime.ino, 5_functionsforanimation.ino, LedMatrixESP.ino]
2021-03-16 New rewrite of the Led Matrix Clock
    Added new features and abilities. Also made it faster
2021-03-16 Create LedMatrixESP2
    Version 2 of the Led Matrix code
2021-03-16 Added new Arduino project files
    A totally new version of the Led Matrix clock software has been written
2021-04-01 There were a few minor bugs, but annoying..
    Accesspoint mode could crash because of not finding alternative SSIDs. this is solved
    WIntertime/summertime issue solved.
    Added the option now to also use a light dependent resistor to automatically change brightness :! cool
    [01_MATRIX_FUNCTIONS.ino, 02_WIFI.ino, 03_ANIMATION_FUNCTIONS.ino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]
2021-10-05 Updated with better HTML interface and LDR
    Now you can use a Light Dependent Resistor to automatically dim when its dark, and make the matrix brighter when the lights are on (or when its sunny).
    Also the HTML website with settings has been cleaned up.
2021-10-07 New animation and settings
    Added animation, every minute or hour the digit will scroll to a new digit..
    Also added in the webinterface the option to select pin 2, 12 or 18 as datapin and you can set the LDR pin. Where pin 0 means no LDR
